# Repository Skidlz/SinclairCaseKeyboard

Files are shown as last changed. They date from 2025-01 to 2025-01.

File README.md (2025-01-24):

# Sinclair Case & Keyboard
A new case and keyboard for the Timex Sinclair 1000 computer

Includes design files for:
* acrylic case
* keyboard pcb
* keyboard plate
* keyboard flat flex cable
  
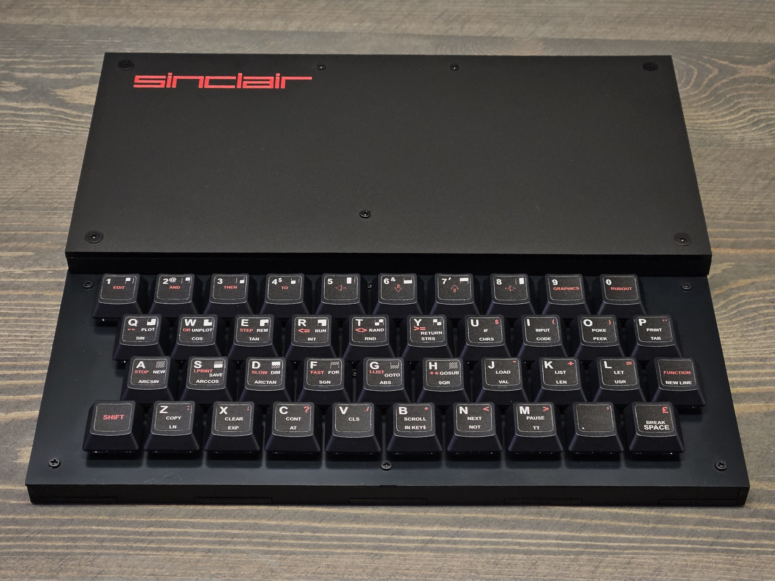
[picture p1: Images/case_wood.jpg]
Finsihed Case


### Case
The case was designed using Inkscape and cut at Ponoko using their 3.00mm "Black Matte Acrylic"

The text was painted using Tamiya "TS-27 Matt White" and Testors "1250T Flat Red"

### PCBs
The boards were designed in Eagle CAD and fabbed at JLCPCB

The plate is 1.2mm black FR-4 (select "Remove Mark")

The flex cable is 0.11mm with a 0.20mm polyimide stiffener

### Keyboard
The switches are blue Redragon low profile

The keycaps were taken from a Redragon K603 keyboard

The key labels come from [4keyboard.com](https://www.4keyboard.com/commodore-keyboard-stickers/647-3006-sinclair-zx-spectrum-non-transparent-keyboard-stickers.html)

# Modifications
The motherboard has to be modified to fit the new case. This means removing the RF modulator, voltage regulator, and heatsink.

I chose to replace the modulator with a composite video board from [Ginger Electronic](https://www.ginger-electronic.com/en/retro-computer/21-zx8-ccb-video-mod-for-sinclair-zx80-and-zx81.html).

The regulator was replaced with a generic buck converter that fits in the TO-220 footprint.

# Images

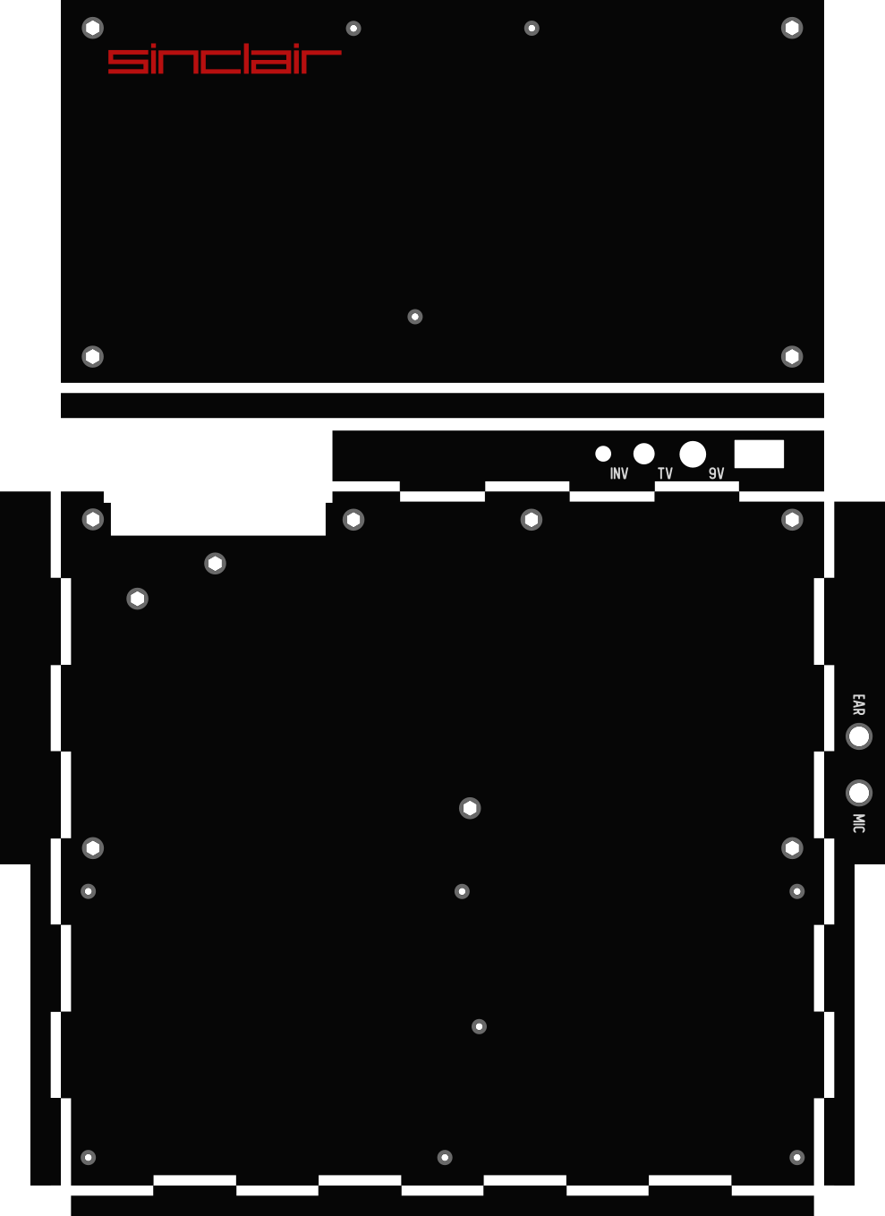
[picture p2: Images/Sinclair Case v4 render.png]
Case


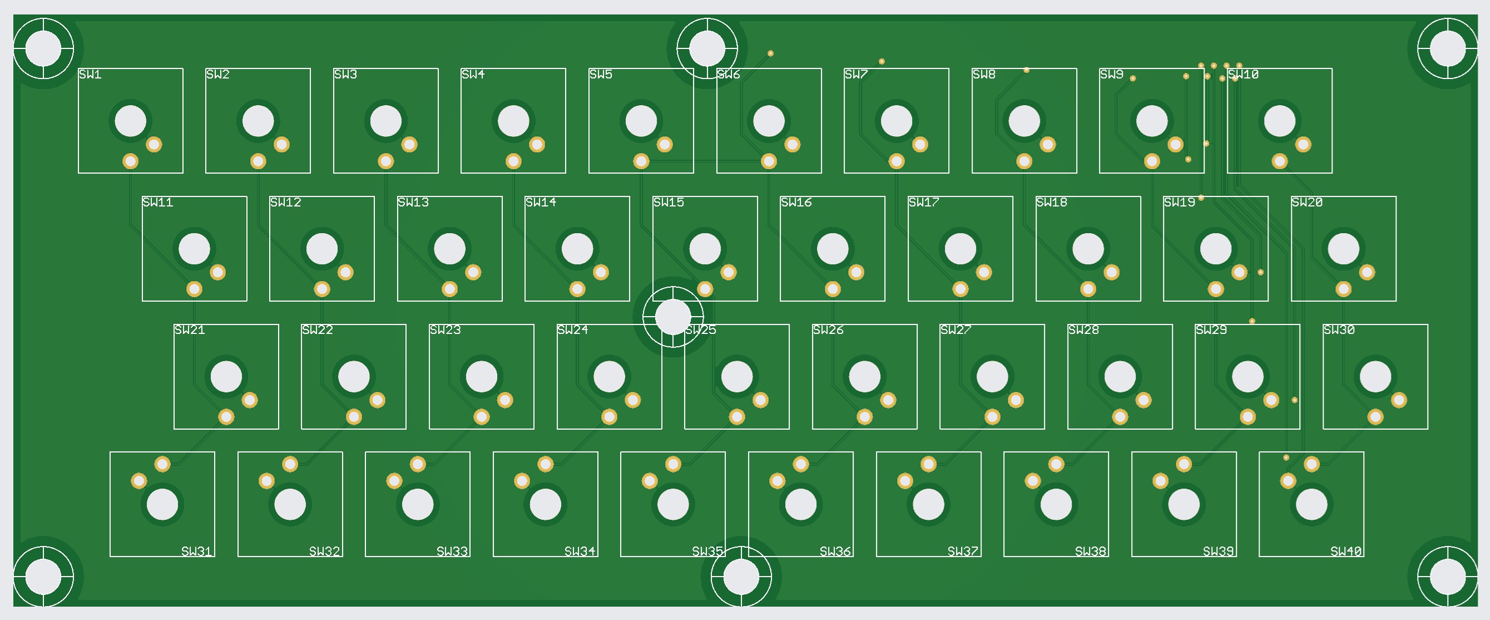
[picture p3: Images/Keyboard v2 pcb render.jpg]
Keyboard PCB


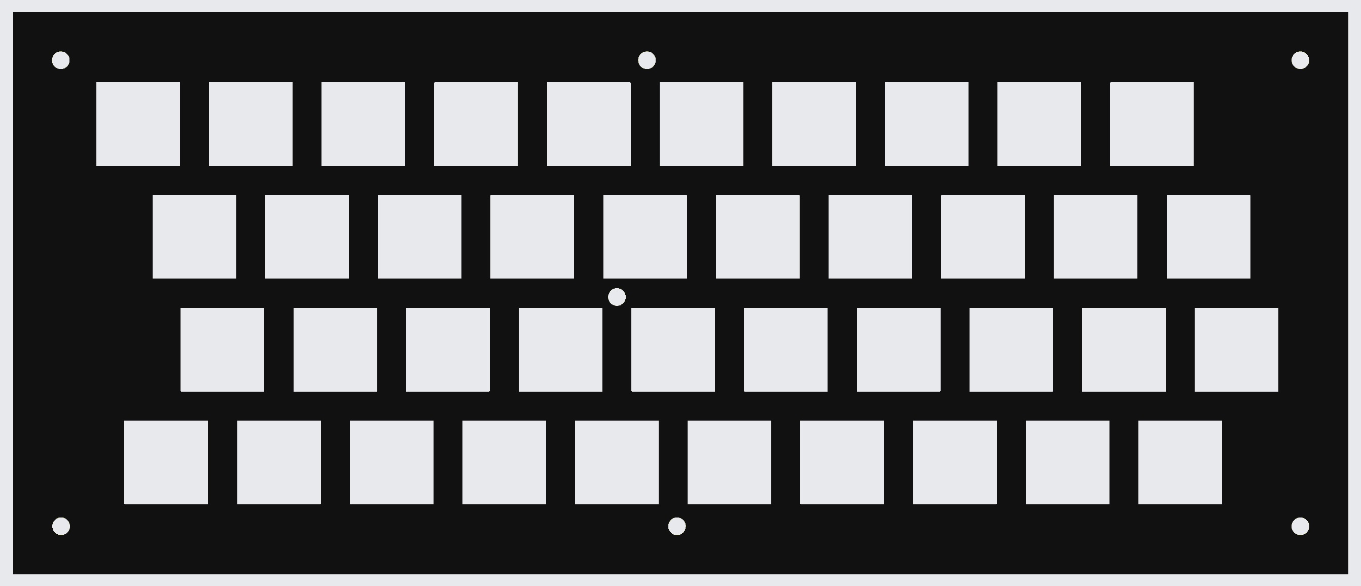
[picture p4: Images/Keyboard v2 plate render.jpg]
Plate


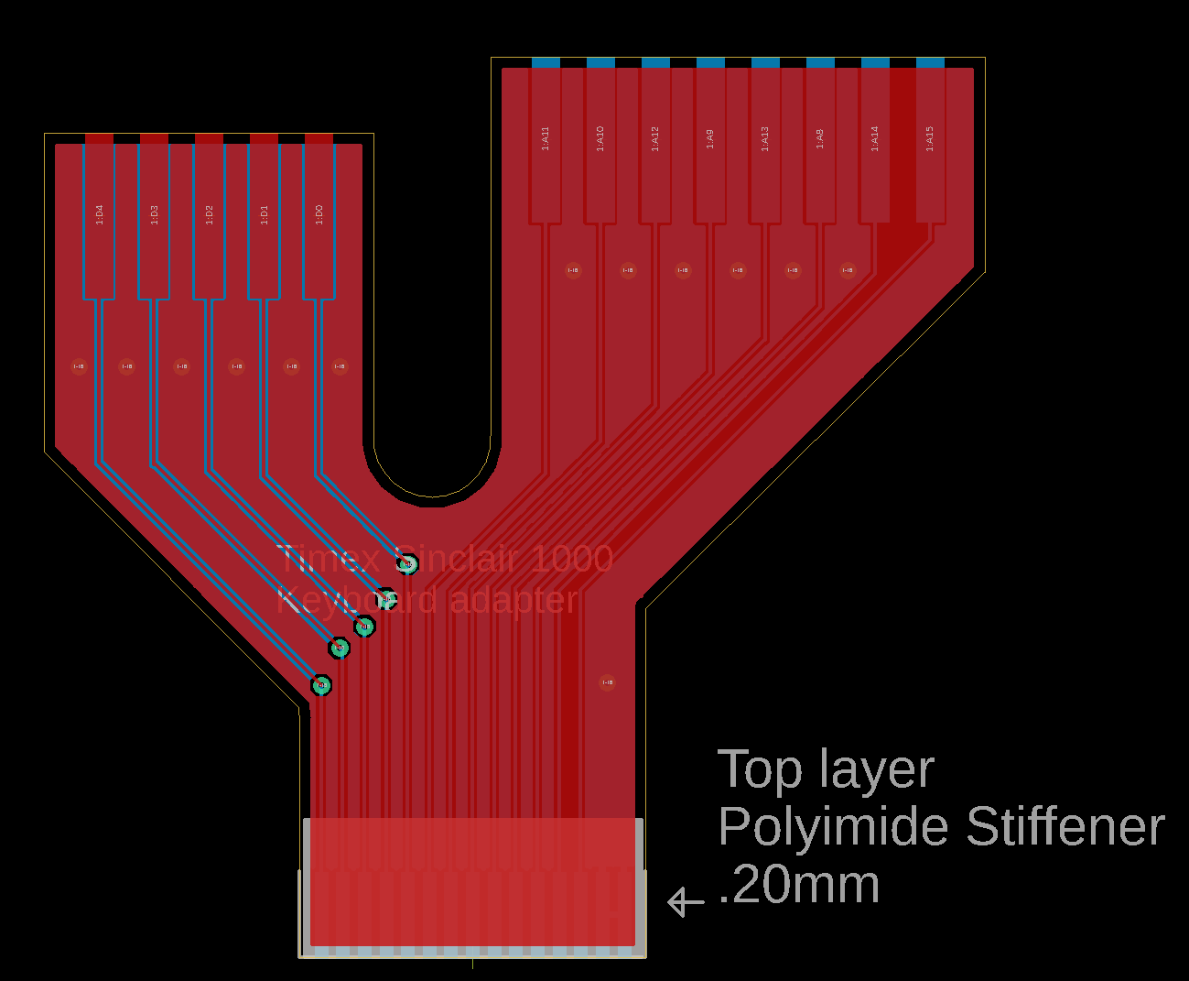
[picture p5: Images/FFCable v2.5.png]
Flex Cable


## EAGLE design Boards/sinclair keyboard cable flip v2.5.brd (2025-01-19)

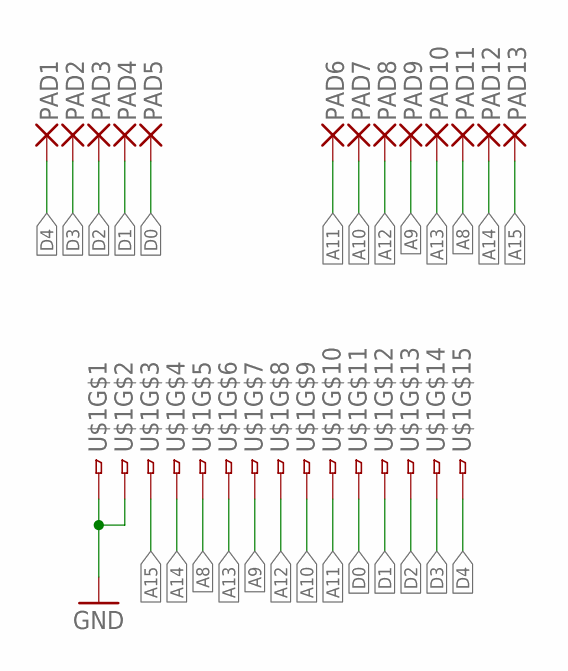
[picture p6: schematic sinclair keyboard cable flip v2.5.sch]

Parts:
PAD1, PAD2, PAD3, PAD4, PAD5, PAD6, PAD7, PAD8, PAD9, PAD10, PAD11, PAD12, PAD13: SMD230MIL; SMD1,27-762
U$1: FH12-15S-1SHFFC; FFC-15

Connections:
A8: PAD11.1, U$1.5
A9: PAD9.1, U$1.7
A10: PAD7.1, U$1.9
A11: PAD6.1, U$1.10
A12: PAD8.1, U$1.8
A13: PAD10.1, U$1.6
A14: PAD12.1, U$1.4
A15: PAD13.1, U$1.3
D0: PAD5.1, U$1.11
D1: PAD4.1, U$1.12
D2: PAD3.1, U$1.13
D3: PAD2.1, U$1.14
D4: PAD1.1, U$1.15
GND: U$1.1, U$1.2

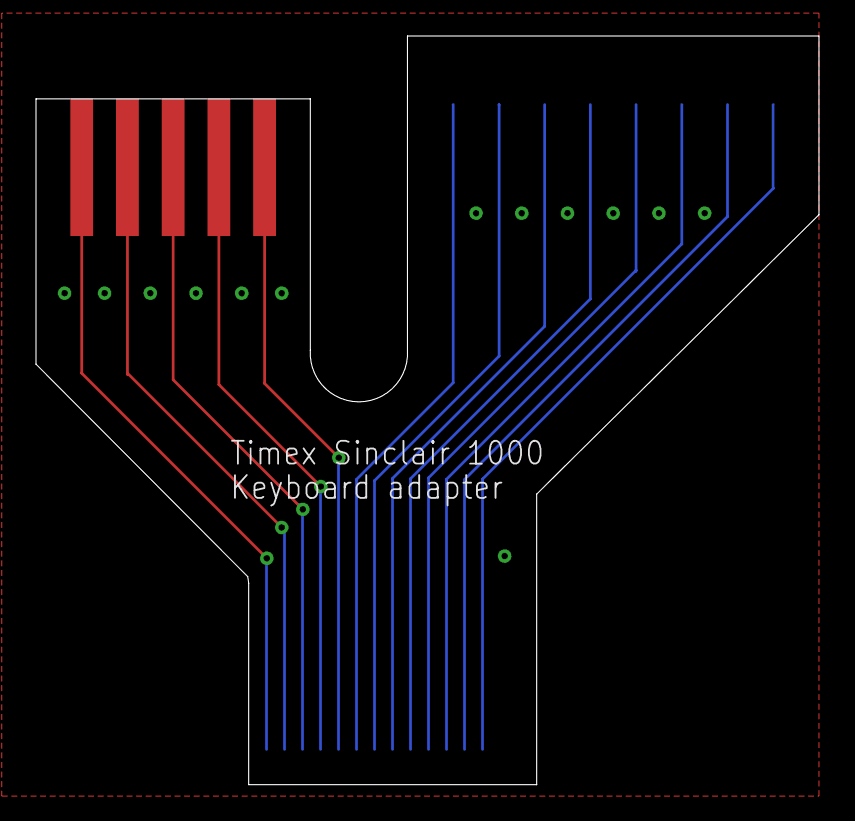
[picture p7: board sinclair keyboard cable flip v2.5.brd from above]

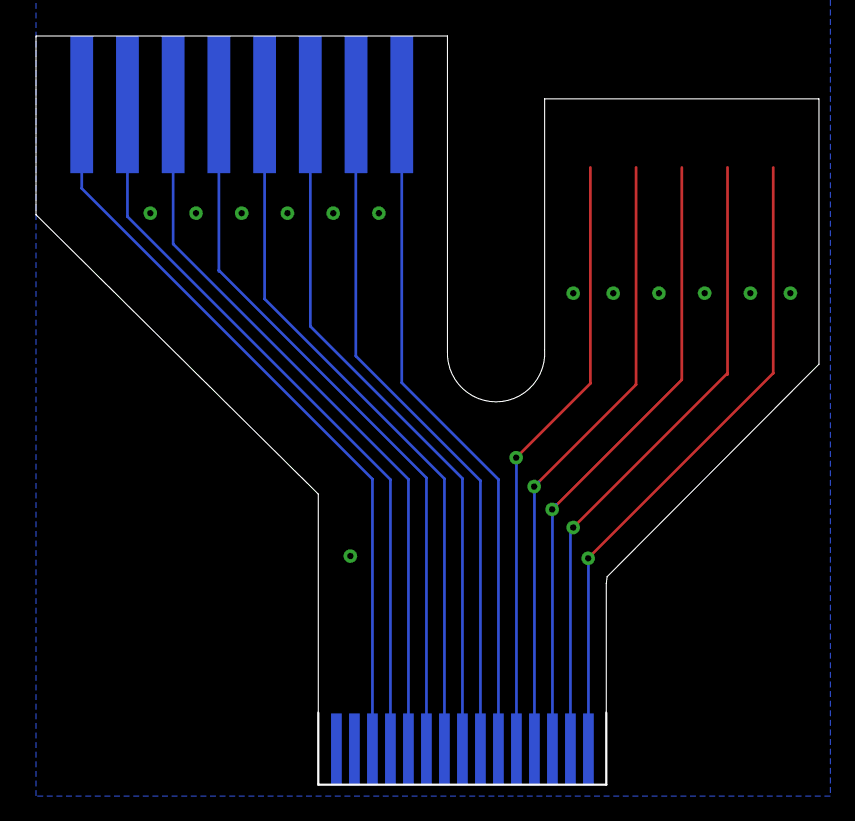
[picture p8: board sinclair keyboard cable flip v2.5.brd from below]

Board: 2 copper layers, 43.5 x 41.6 mm, 14 parts (9 on the bottom side), 14 nets.

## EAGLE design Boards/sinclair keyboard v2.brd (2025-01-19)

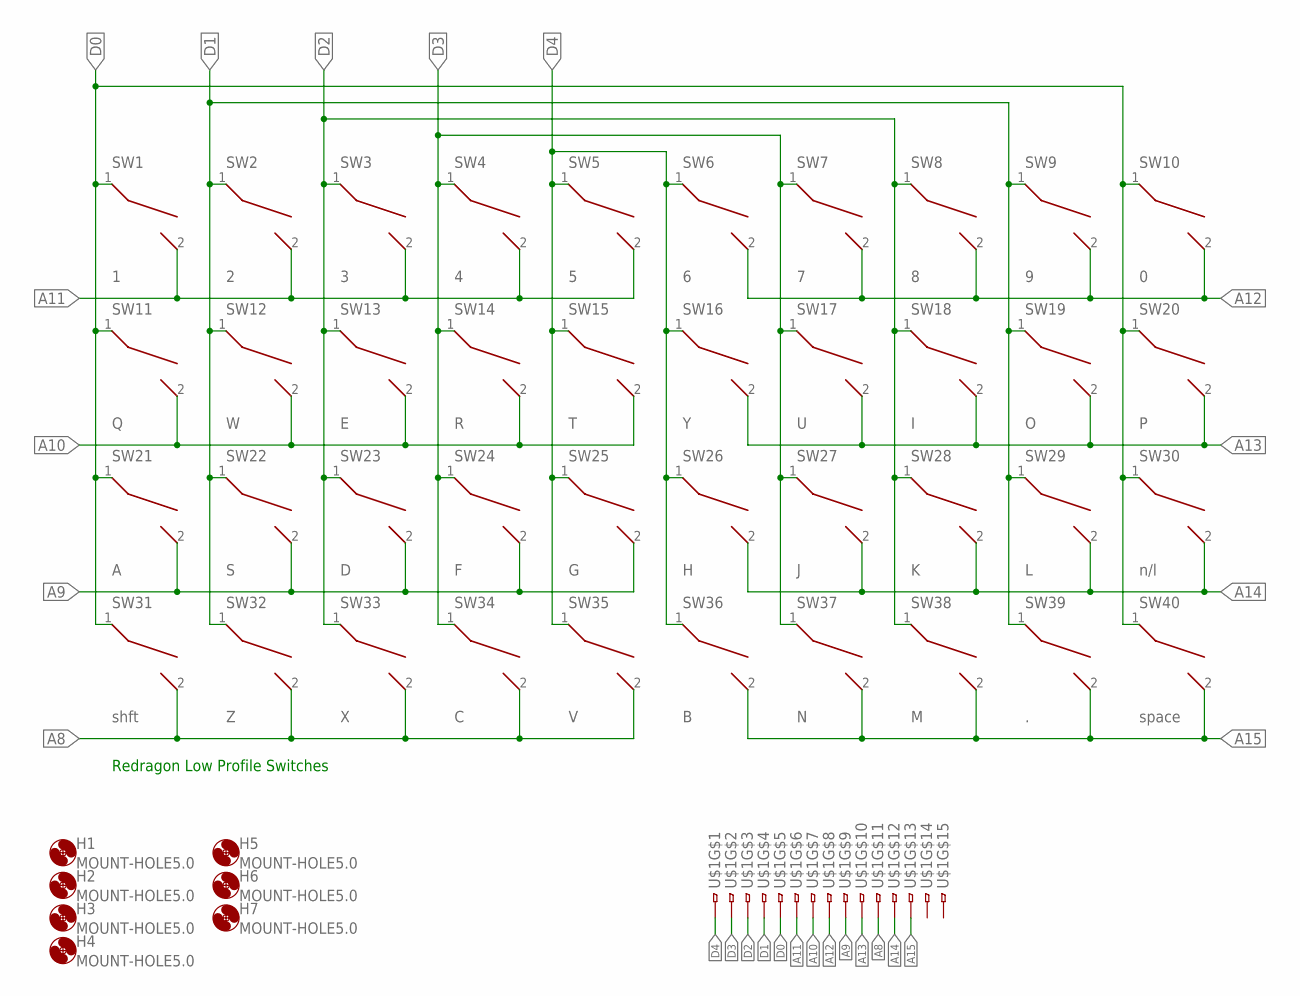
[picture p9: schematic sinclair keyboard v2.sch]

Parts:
H1, H2, H3, H4, H5, H6, H7: MOUNT-HOLE5.0; 5,0
SW1: 1; REDRAGON_LOWPROFILE
SW2: 2; REDRAGON_LOWPROFILE
SW3: 3; REDRAGON_LOWPROFILE
SW4: 4; REDRAGON_LOWPROFILE
SW5: 5; REDRAGON_LOWPROFILE
SW6: 6; REDRAGON_LOWPROFILE
SW7: 7; REDRAGON_LOWPROFILE
SW8: 8; REDRAGON_LOWPROFILE
SW9: 9; REDRAGON_LOWPROFILE
SW10: 0; REDRAGON_LOWPROFILE
SW11: Q; REDRAGON_LOWPROFILE
SW12: W; REDRAGON_LOWPROFILE
SW13: E; REDRAGON_LOWPROFILE
SW14: R; REDRAGON_LOWPROFILE
SW15: T; REDRAGON_LOWPROFILE
SW16: Y; REDRAGON_LOWPROFILE
SW17: U; REDRAGON_LOWPROFILE
SW18: I; REDRAGON_LOWPROFILE
SW19: O; REDRAGON_LOWPROFILE
SW20: P; REDRAGON_LOWPROFILE
SW21: A; REDRAGON_LOWPROFILE
SW22: S; REDRAGON_LOWPROFILE
SW23: D; REDRAGON_LOWPROFILE
SW24: F; REDRAGON_LOWPROFILE
SW25: G; REDRAGON_LOWPROFILE
SW26: H; REDRAGON_LOWPROFILE
SW27: J; REDRAGON_LOWPROFILE
SW28: K; REDRAGON_LOWPROFILE
SW29: L; REDRAGON_LOWPROFILE
SW30: n/l; REDRAGON_LOWPROFILE
SW31: shft; REDRAGON_LOWPROFILE
SW32: Z; REDRAGON_LOWPROFILE
SW33: X; REDRAGON_LOWPROFILE
SW34: C; REDRAGON_LOWPROFILE
SW35: V; REDRAGON_LOWPROFILE
SW36: B; REDRAGON_LOWPROFILE
SW37: N; REDRAGON_LOWPROFILE
SW38: M; REDRAGON_LOWPROFILE
SW39: .; REDRAGON_LOWPROFILE
SW40: space; REDRAGON_LOWPROFILE
U$1: FH12-15S-1SH

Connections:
A8: SW31.2, SW32.2, SW33.2, SW34.2, SW35.2, U$1.11
A9: SW21.2, SW22.2, SW23.2, SW24.2, SW25.2, U$1.9
A10: SW11.2, SW12.2, SW13.2, SW14.2, SW15.2, U$1.7
A11: SW1.2, SW2.2, SW3.2, SW4.2, SW5.2, U$1.6
A12: SW6.2, SW7.2, SW8.2, SW9.2, SW10.2, U$1.8
A13: SW16.2, SW17.2, SW18.2, SW19.2, SW20.2, U$1.10
A14: SW26.2, SW27.2, SW28.2, SW29.2, SW30.2, U$1.12
A15: SW36.2, SW37.2, SW38.2, SW39.2, SW40.2, U$1.13
D0: SW1.1, SW10.1, SW11.1, SW20.1, SW21.1, SW30.1, SW31.1, SW40.1, U$1.5
D1: SW2.1, SW9.1, SW12.1, SW19.1, SW22.1, SW29.1, SW32.1, SW39.1, U$1.4
D2: SW3.1, SW8.1, SW13.1, SW18.1, SW23.1, SW28.1, SW33.1, SW38.1, U$1.3
D3: SW4.1, SW7.1, SW14.1, SW17.1, SW24.1, SW27.1, SW34.1, SW37.1, U$1.2
D4: SW5.1, SW6.1, SW15.1, SW16.1, SW25.1, SW26.1, SW35.1, SW36.1, U$1.1

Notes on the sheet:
Redragon Low Profile Switches

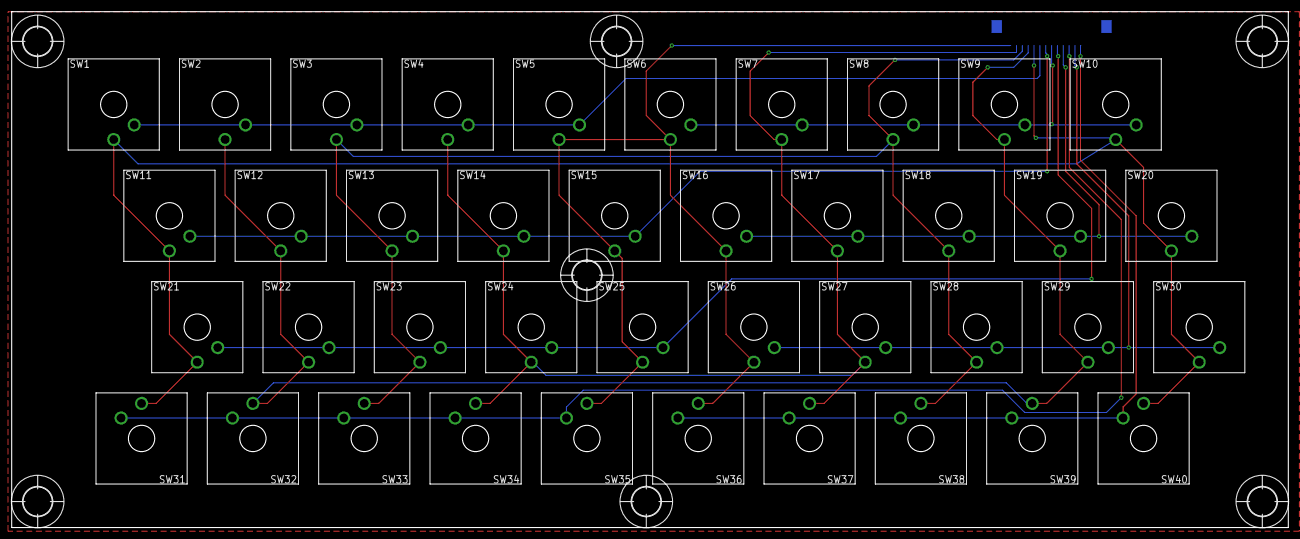
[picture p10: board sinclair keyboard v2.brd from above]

Board: 2 copper layers, 218.4 x 88.3 mm, 48 parts (1 on the bottom side), 13 nets.
